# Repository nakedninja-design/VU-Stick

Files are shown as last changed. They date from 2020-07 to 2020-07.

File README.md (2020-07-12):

Party VU Stick
--------------

The Party VU Stick is a vertical LED VU meter you can stick in the ground. It listens to the FM radio channel you have set (10 presets or custom) and lights up a rainbow of colors that follow the dynamics of the music that is playing. Very easy to build and assemble, and a 8-year old child can set it up. 

STL files, source code and documentation available within 2 weeks.

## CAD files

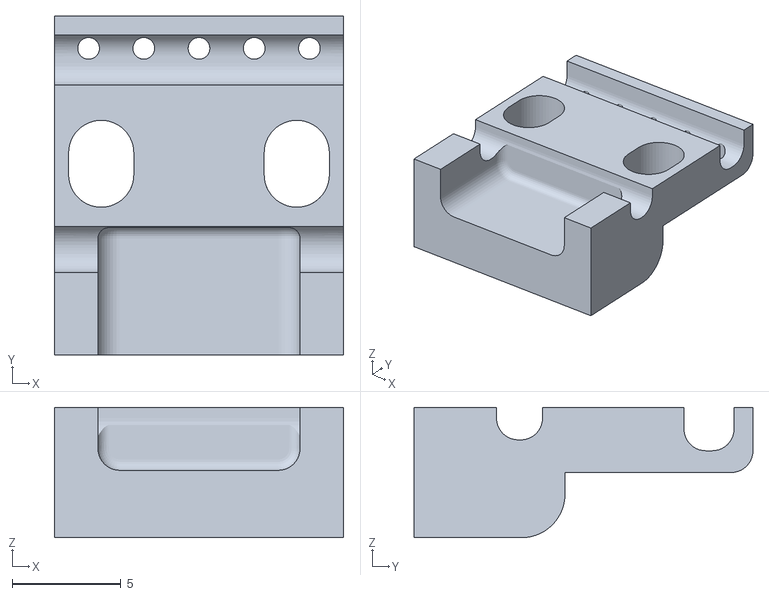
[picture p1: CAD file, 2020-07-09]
STL files/micro usb clamp.stl
13.3 x 15.6 x 6.00

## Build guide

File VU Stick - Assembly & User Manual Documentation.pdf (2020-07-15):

Copyright © 2020 Naked Ninja

### Contents

The Product | 2
Bill of Materials | 3
PCB Assembly Instructions | 4
Software Assembly & Testing | 17
3D Printing & Assembly | 19
User Manual | 33
Basic Information | 33
Connecting power | 36
Adding preset FM stations | 38
Switching between preset FM stations | 40
Setting manual FM frequency | 41
Calibrating RGB LED strip | 42
1 | Copyright © 2020 Naked Ninja

## The Product

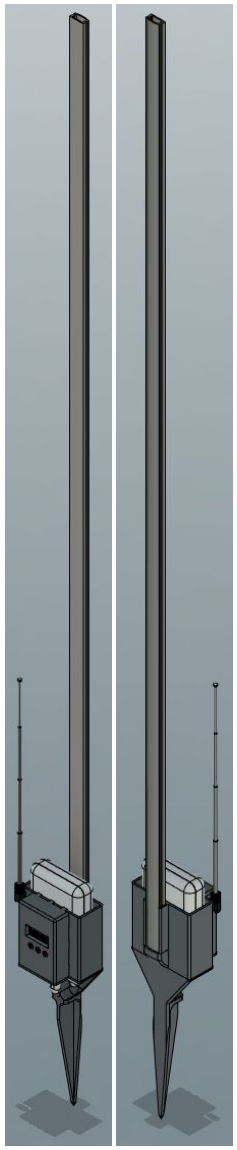
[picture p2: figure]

If you have soldering experience and are not intimidated by soldering tiny pins in tight spaces, then this build level should be appropriate for you. Make sure to use the proper soldering iron, solder wire, and solder paste for this project. Check the orientation of components before you solder them to the board. The wrong orientation may damage the components, the board, etc!

Naked Ninja does not take any responsibility and is not liable for any damage resulting from the use of products or services from Naked Ninja, be it indirect, special, incidental or consequential damages (including but not limited to damages for loss of business, loss of profits, interruption or the like).

When you have a garden party, wouldn't it be fun to have several VU meters spread throughout the garden with RGB LEDs dancing to the music you are playing? That's what the Party VU Stick is all about.

The Party VU Stick can connect to any FM radio station and dance along with the music. Want the VU Stick to dancing along with your music? It’s simple! Just add an FM transmitter to your phone and set the frequency on the VU Stick and you are done.

## Bill of Materials

We have no affiliation with AliExpress, Banggood, RS-Online, or any other supplier of components. You can use any source you like. If you want to order from another supplier, you can use the links listed below as a source for the specifications of the components.

Naked Ninja VU Stick PCB
Naked Ninja webshop (https://nakedninja.cc/)

I2C 0.91 Inch Oled Display (with PCB) https://aliexpress.com/item/32672229793.html

### 3 x Tactile Push Button 6x6x4.3mm

https://aliexpress.com/item/32960657626.html

2.54mm 3Pin Angled Male JST connector & Female Cable JST Connector (for RGB strip) https://aliexpress.com/item/4000120545240.html

5V 16MHz Arduino Pro mini
Pay attention to the A4 and A5 pin locations if you buy it from a dif erent supplier! https://www.digikey.nl/product-detail/en/sparkfun-electronics/DEV-11113/1568-1055-ND/5 140820 (https://www.digikey.nl/product-detail/en/sparkfun-electronics/DEV-11113/1568-1055-ND/5140820)

TEA5767 FM Stereo Radio Module
Pay attention to the pin locations if you buy it from a dif erent supplier! https://aliexpress.com/item/4000279468853.html

Micro USB breakout board
https://aliexpress.com/item/4000385426649.html

Powerbank with a micro USB cable https://aliexpress.com/item/4000731178541.html

RGB LED Strip - 1M 60 IP30 option (60 LEDs) https://aliexpress.com/item/32966375934.html

### 5 x Self-tapping Screw M3 8mm

https://aliexpress.com/item/32596628894.html

Resistors (2x 4.7k Ohm, 2x 10k Ohm, 1x 100k Ohm, 1x 470 Ohm) https://aliexpress.com/item/32636020144.html (Set of resistors) https://aliexpress.com/item/32847096736.html (Individual resistors)

Capacitors (1x 10uF, 1x 100uF) https://aliexpress.com/item/32500862928.html (Set of capacitors) https://aliexpress.com/item/32887486570.html (Individual capacitors)

## PCB Assembly Instructions

The following paragraphs will explain how to assemble the VU Stick PCB. Follow each step precisely to ensure everything will work properly.

1. Start with the VU Stick PCB (photo 1 & 2) and the required components named in the bill of materials.

Photo 1 & 2: Front and back view of the VU Stick V1.2 PCB

2. Place and solder the three tactile buttons on the PCB

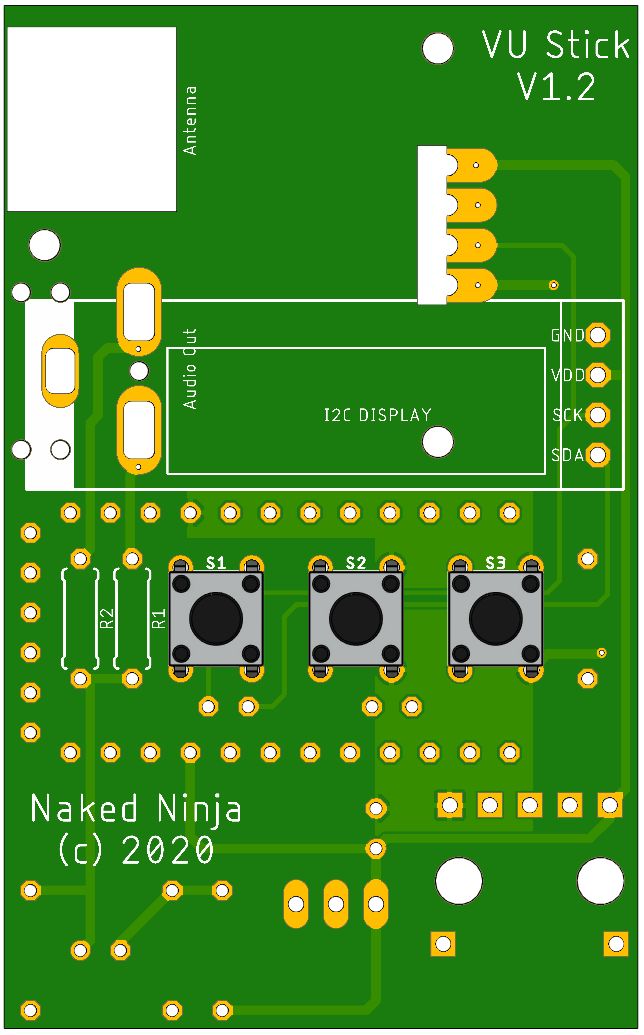
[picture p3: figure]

Photo 3: Front view of the VU Stick V1.2 PCB with tactile buttons placed and soldered.

3. Shorten the pins of the tactile buttons after they are soldered.
Note: This is done to prevent the button pins of touching the microcontroller board that will be soldered in future steps.

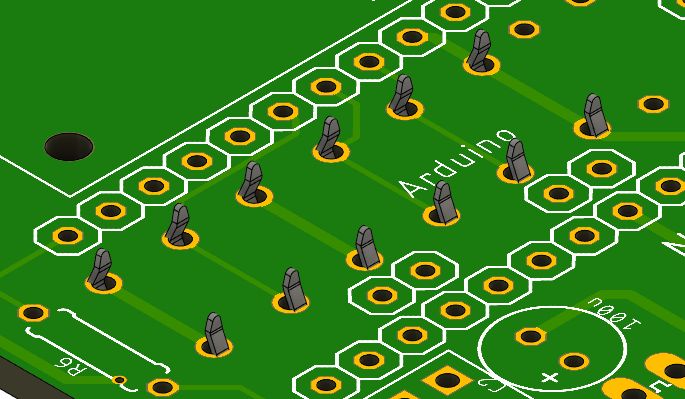
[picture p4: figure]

Photo 4: Back view of the VU Stick V1.2 PCB with tactile buttons pins sticking out of PCB.

4. Place and solder two 4.7k ohm resistors in the R1 and R2 slots next to the tactile buttons as illustrated in photo 5.

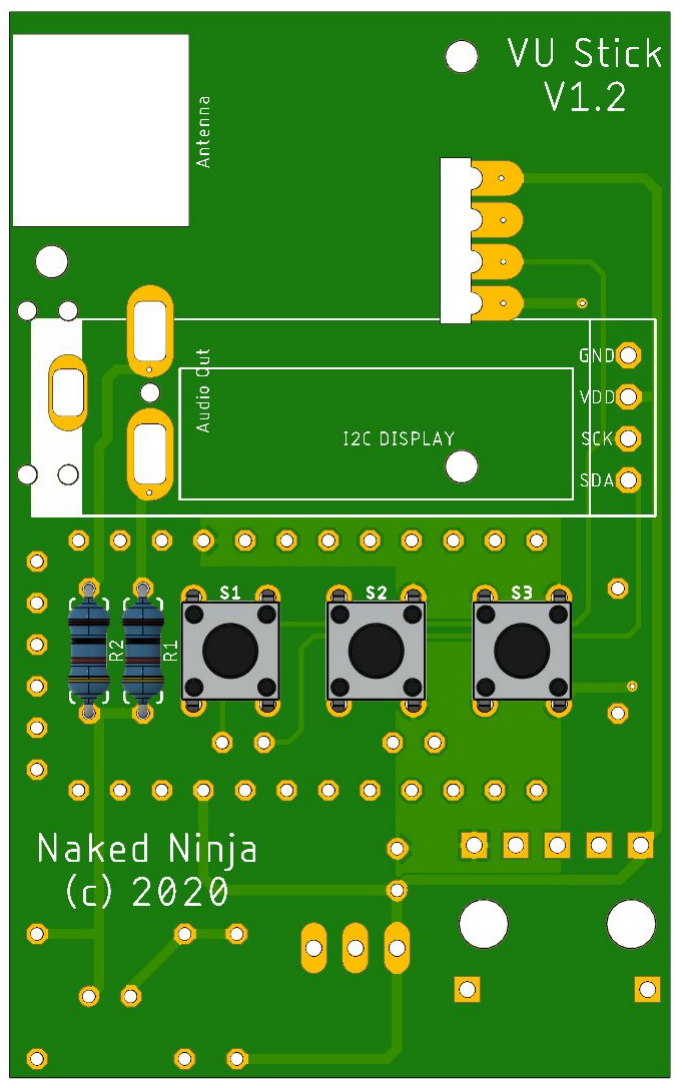
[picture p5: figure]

Photo 5: Front view of the VU Stick V1.2 PCB with resistor R1 and R2 placed and soldered.

5. Shorten the pins of the two resistors after they are soldered.
Note: This is done to prevent the resistor pins of touching the microcontroller board that will be soldered in future steps.

Photo 6: Back view of the VU Stick V1.2 PCB with shortened soldered resistor R1 and R2 pins.

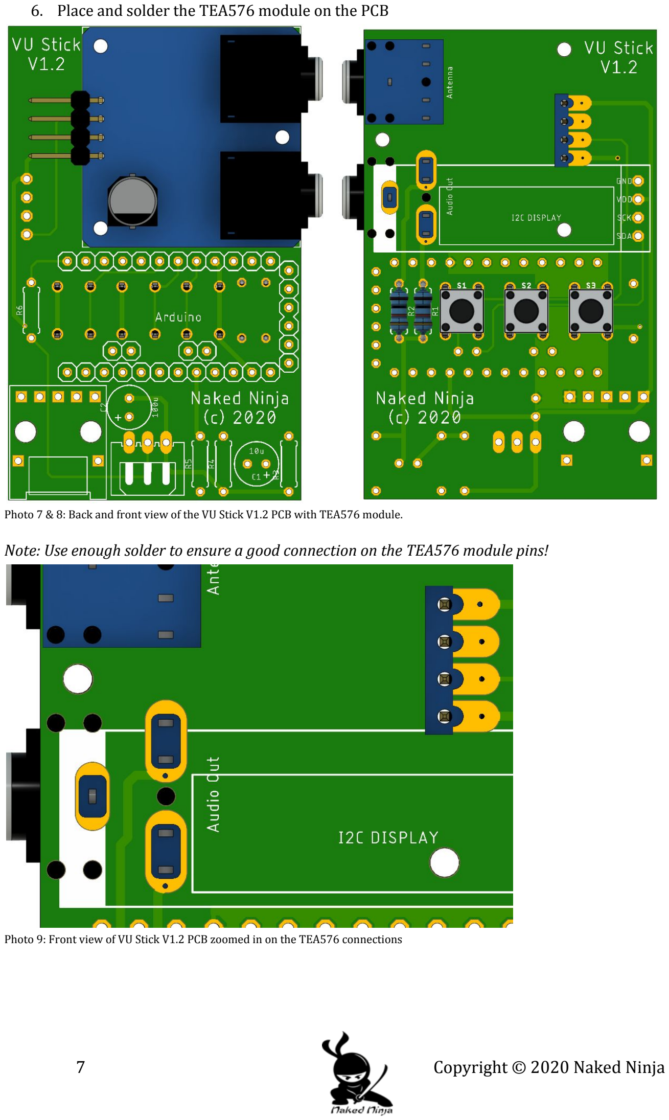
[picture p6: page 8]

6. Place and solder the TEA576 module on the PCB

Photo 7 & 8: Back and front view of the VU Stick V1.2 PCB with TEA576 module.

Note: Use enough solder to ensure a good connection on the TEA576 module pins!

Photo 9: Front view of VU Stick V1.2 PCB zoomed in on the TEA576 connections

7. Place and solder resistors in the R3, R4, R5 and R6 slots as illustrated in photo 10 with the following values per slot:
R3: 100k ohm
R4: 10k ohm
R5: 10k ohm
R6: 470 ohm

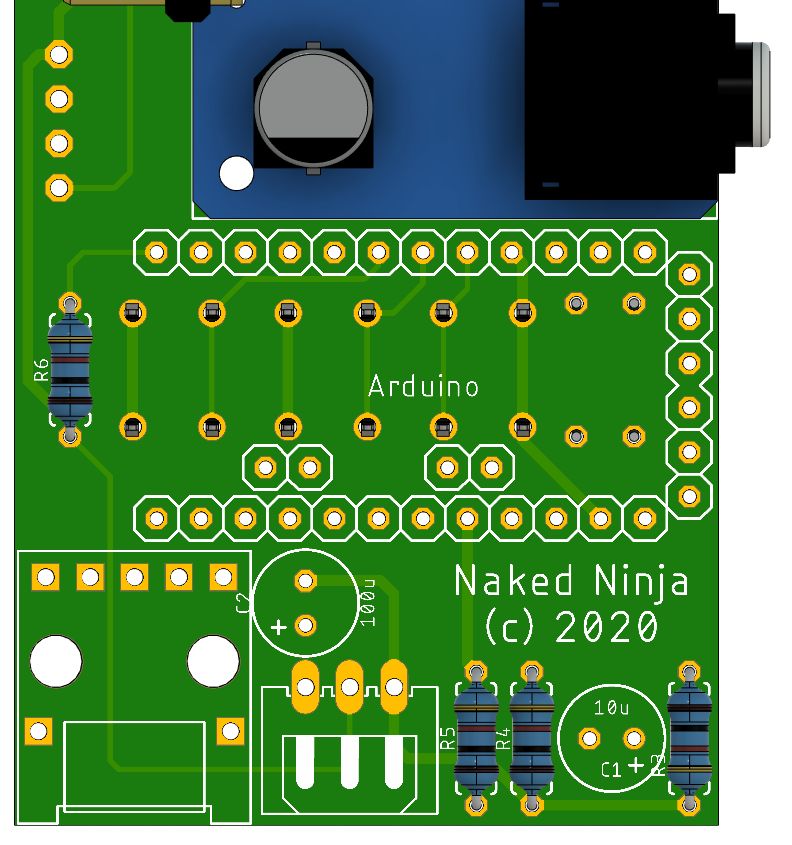
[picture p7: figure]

Photo 10: Back view of VU Stick V1.2 PCB with resistor R3, R4, R5 and R6 placed and soldered

8. Place and solder the capacitors in the C1 and C2 slots as illustrated in photo 11 and 12 with the following values per slot:
C1: 10uF
C2: 100uF
Note: Be sure to solder the plus terminal of the capacitor to the marked + on the PCB.

Photo 11: Back view of VU Stick V1.2 PCB with capacitor C1 and C2 placed and soldered

Photo 12: Angled back view of VU Stick V1.2 PCB with capacitor C1 and C2 placed and soldered

9. Place male pin header in the slots for the Arduino Pro Mini as illustrated in photo 13.

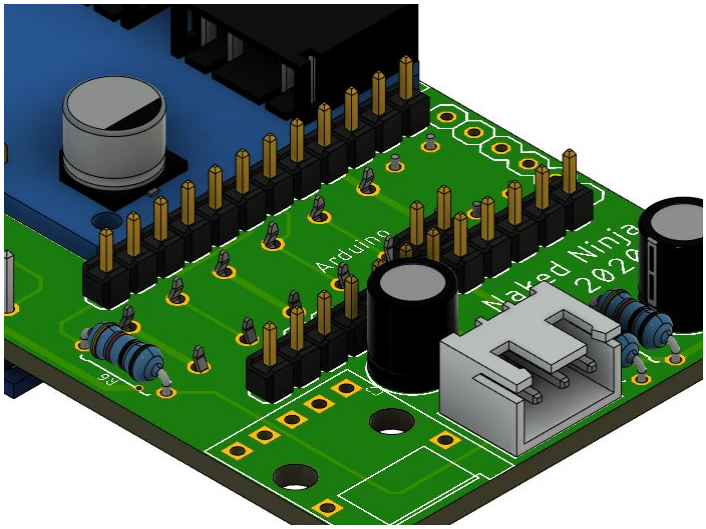
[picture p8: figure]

Photo 13: Angle back view of VU Stick V1.2 PCB with male headers

Note:
If you are using a dif erent type of the Arduino Pro Mini, make sure the following pins are connected: A3, A4(SDA), A5(SCL), D2, D3, D4, and D9.

10. Place the Arduino Pro Mini on the male headers and solder the male headers to the Arduino Pro Mini.

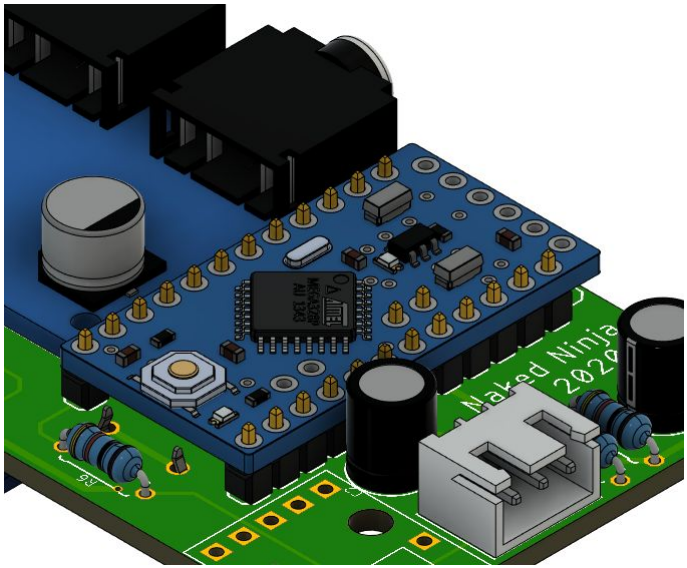
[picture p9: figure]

Photo 14: Angle back view of VU Stick V1.2 PCB with Arduino Pro Mini soldered to male headers.

11. Solder the male headers to the PCB.

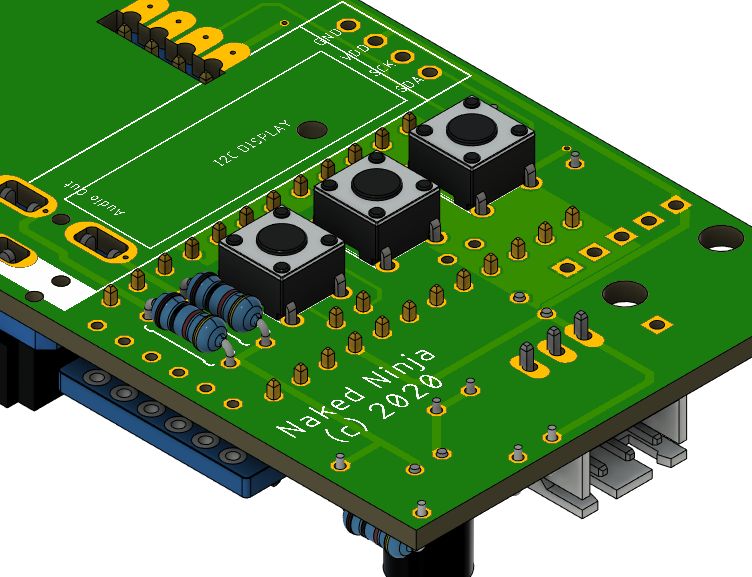
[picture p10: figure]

Photo 15: Angle top view of VU Stick V1.2 PCB with soldered male headers.

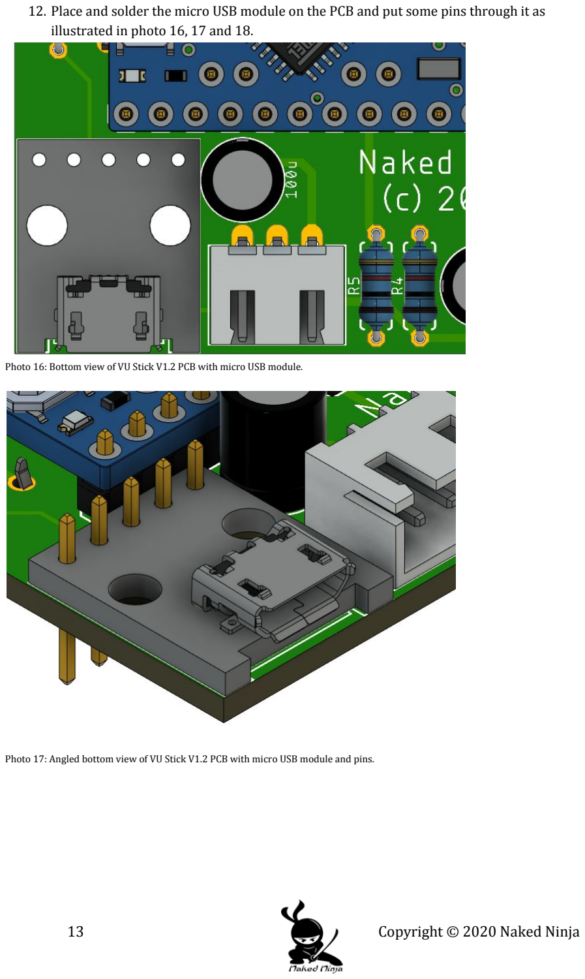
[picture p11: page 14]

12. Place and solder the micro USB module on the PCB and put some pins through it as illustrated in photo 16, 17 and 18.

Photo 16: Bottom view of VU Stick V1.2 PCB with micro USB module.

Photo 17: Angled bottom view of VU Stick V1.2 PCB with micro USB module and pins.

Photo 18: Angled top view of VU Stick V1.2 PCB with micro USB module and pins.

13. Shorten the pins on the micro USB as illustrated in photo 19 and 20 after they are soldered.

Photo 19: Angled top view of VU Stick V1.2 PCB with shortened pins on the micro USB module connection.

Photo 20: Angled top view of VU Stick V1.2 PCB with shortened pins on the micro USB module connection.

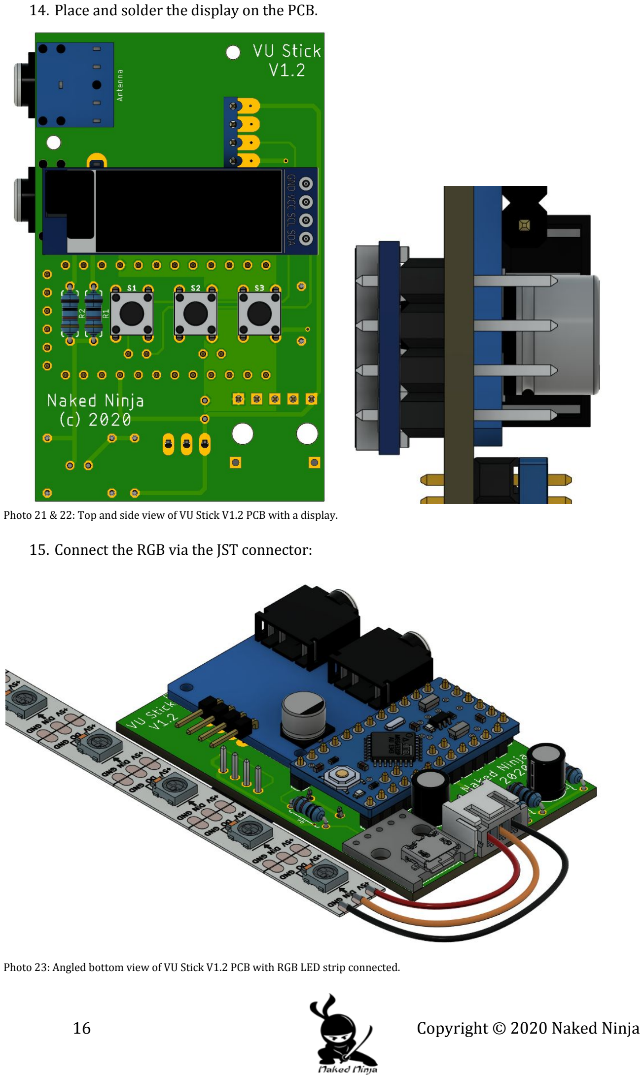
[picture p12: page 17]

14. Place and solder the display on the PCB.

Photo 21 & 22: Top and side view of VU Stick V1.2 PCB with a display.

15. Connect the RGB via the JST connector:

Photo 23: Angled bottom view of VU Stick V1.2 PCB with RGB LED strip connected.

## Software Assembly & Testing

The following paragraphs will explain how to program the VU Stick and how to configure the preset FM radio stations.

Before continuing you must acquire the following items:
- PC or laptop with the Arduino IDE
- USB to TTL converter
- USB cable (to connect the converter to the PC/laptop)
- The Arduino sketch from the Naked Ninja GitHub.

After acquiring all items follow the following steps to program and configure the VU Stick:
1. Download the Arduino sketch for the VU Stick from the Naked Ninja product page or Github.
2. Open sketch in the Arduino IDE.
3. [OPTIONAL] Replace the FM stations in the array radioStations with your preferred stations.
Notes / Warnings:
1. Max of 10 stations can be given. More than this will result in memory problems.

### 2. The first value is the frequency of the station (example: 10270 = 102.7 MHz) and the

second is the name that will show up on the display. This name must be kept short to avoid problems.

Photo 24: Arduino IDE programming screen

4. Connect the USB-TTL converter to the Arduino Pro Mini

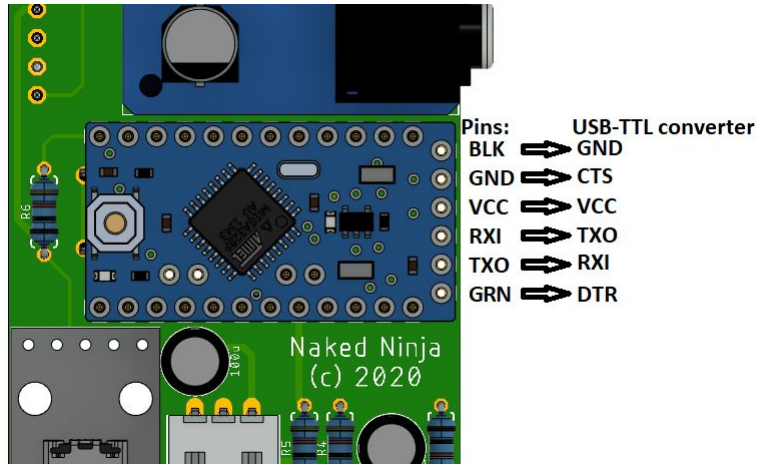
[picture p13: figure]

Photo 25: Arduino Pro Mini connection explanation

5. Connect the USB_TTL converter to the PC/Laptop.
6. Select the correct programming parameters.
Note: The programming parameters can be found in the top of the Arduino sketch
7. Program the Arduino Pro Mini.
8. Disconnect the USB-TTL converter from the Arduino Pro Mini after the programming is completed.
9. Connect the power bank through the micro USB connector and test the PCB using the “User Manual” from this document.

## 3D Printing & Assembly

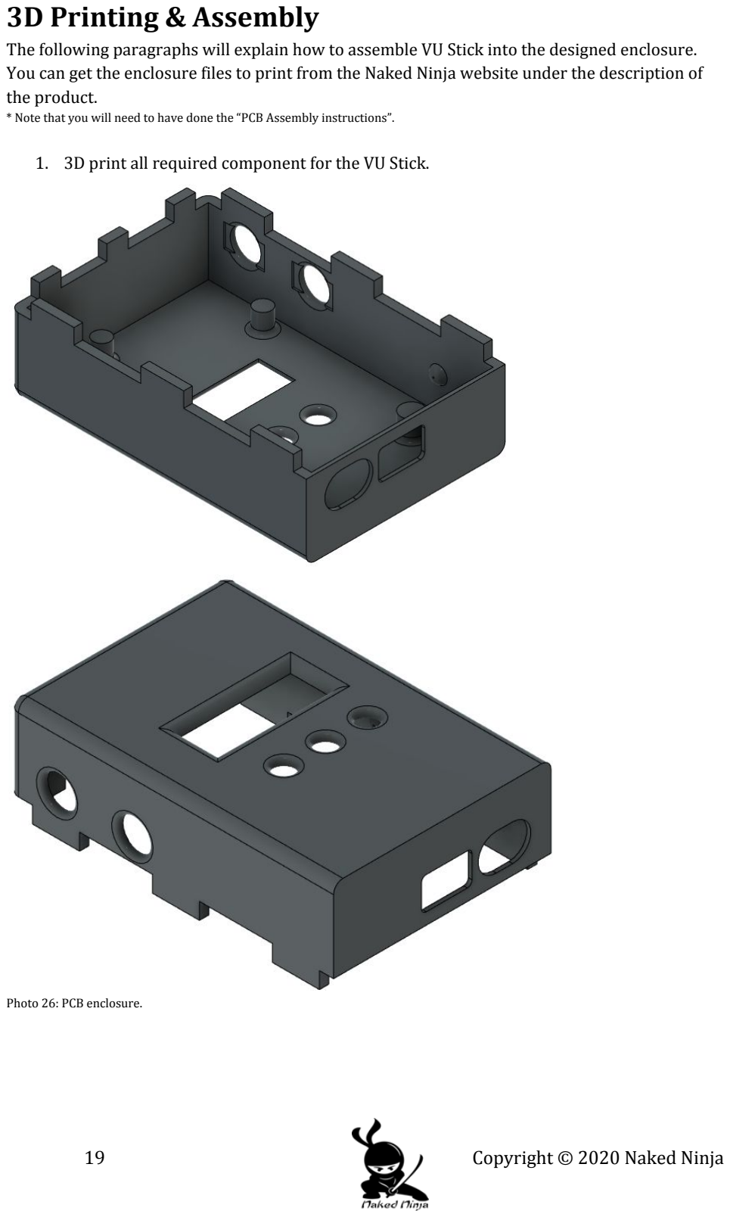
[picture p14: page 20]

The following paragraphs will explain how to assemble VU Stick into the designed enclosure. You can get the enclosure files to print from the Naked Ninja website under the description of the product.

* Note that you will need to have done the “PCB Assembly instructions”.

1. 3D print all required component for the VU Stick.

Photo 26: PCB enclosure.

Photo 27: Battery and RGB profile enclosure.

Photo 28: Spike enclosure.

Photo 29: Button caps

Photo 30: Micro USB cover.

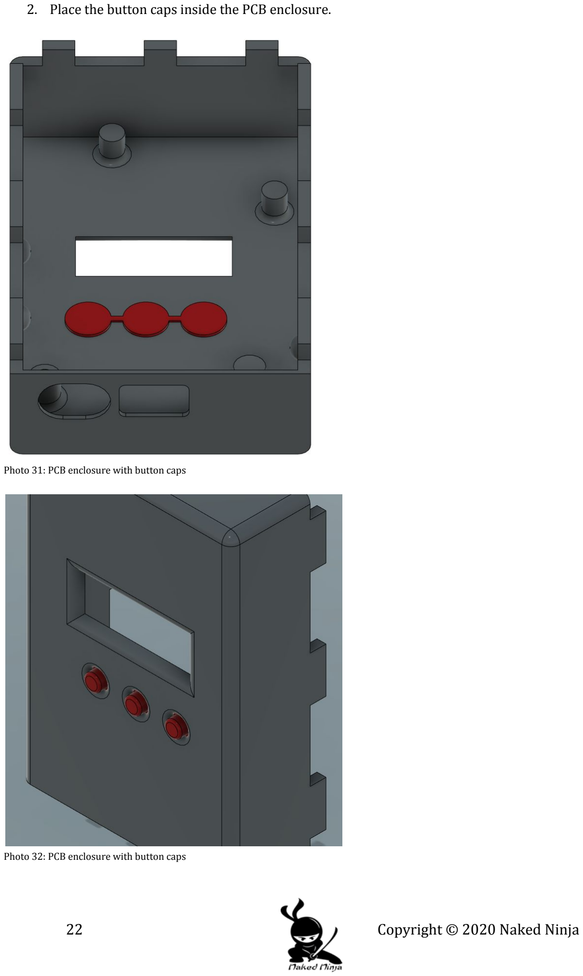
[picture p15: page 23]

2. Place the button caps inside the PCB enclosure.

Photo 31: PCB enclosure with button caps

Photo 32: PCB enclosure with button caps

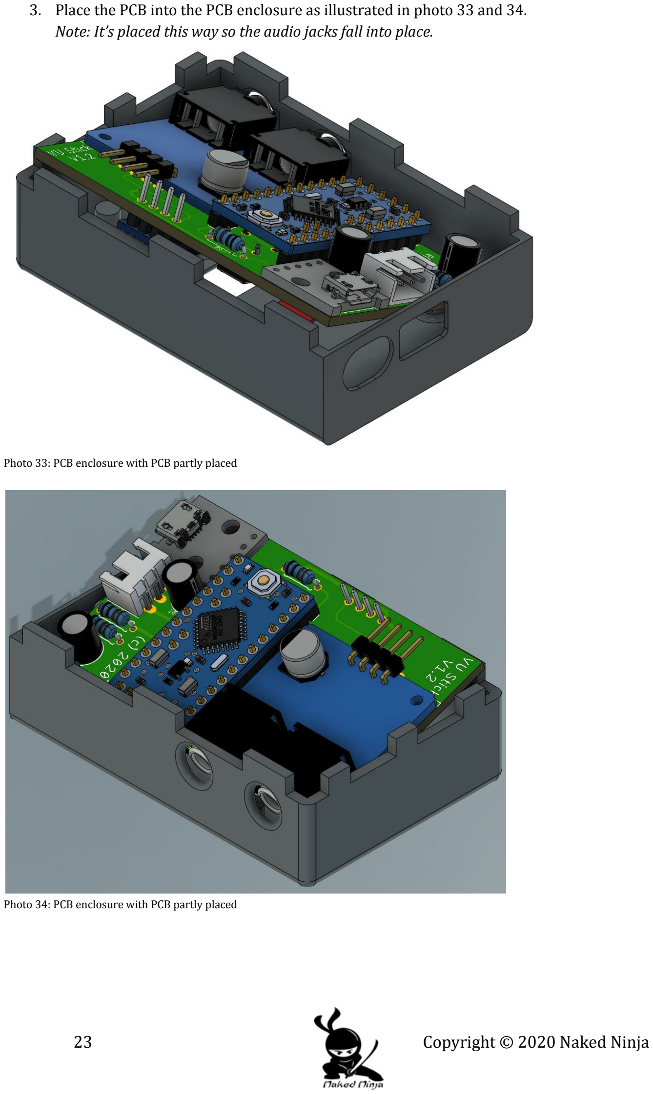
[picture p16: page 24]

3. Place the PCB into the PCB enclosure as illustrated in photo 33 and 34. Note: It’s placed this way so the audio jacks fall into place.

Photo 33: PCB enclosure with PCB partly placed

Photo 34: PCB enclosure with PCB partly placed

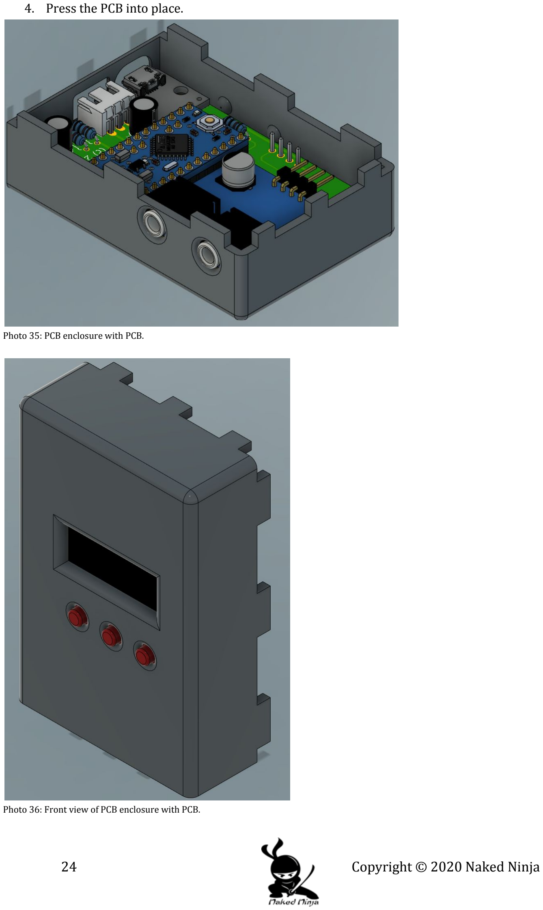
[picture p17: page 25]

4. Press the PCB into place.

Photo 35: PCB enclosure with PCB.

Photo 36: Front view of PCB enclosure with PCB.

5. Place the micro USB cover on the micro USB and screw it down with an M3 6mm screw.

Photo 37: Micro USB cover PCB enclosure with PCB.

Photo 38: Front view of PCB enclosure with PCB.

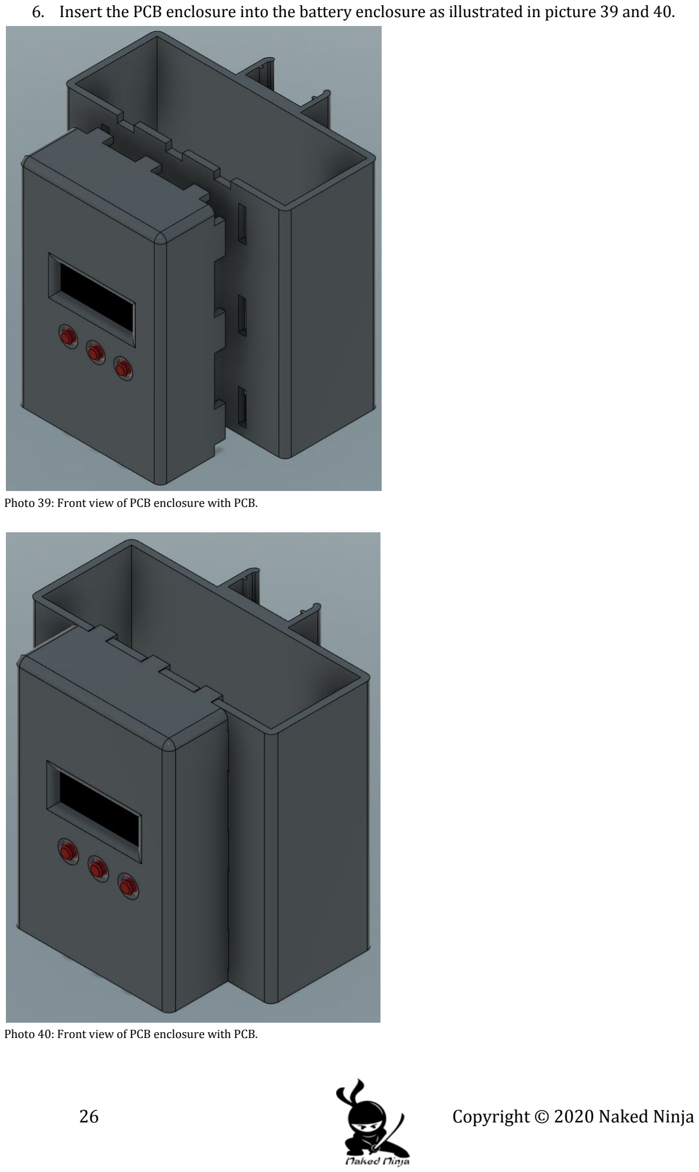
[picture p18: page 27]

6. Insert the PCB enclosure into the battery enclosure as illustrated in picture 39 and 40.

Photo 39: Front view of PCB enclosure with PCB.

Photo 40: Front view of PCB enclosure with PCB.

7. Place the RGB connector cable through the opening in the battery enclosure as illustrated in photo 41.

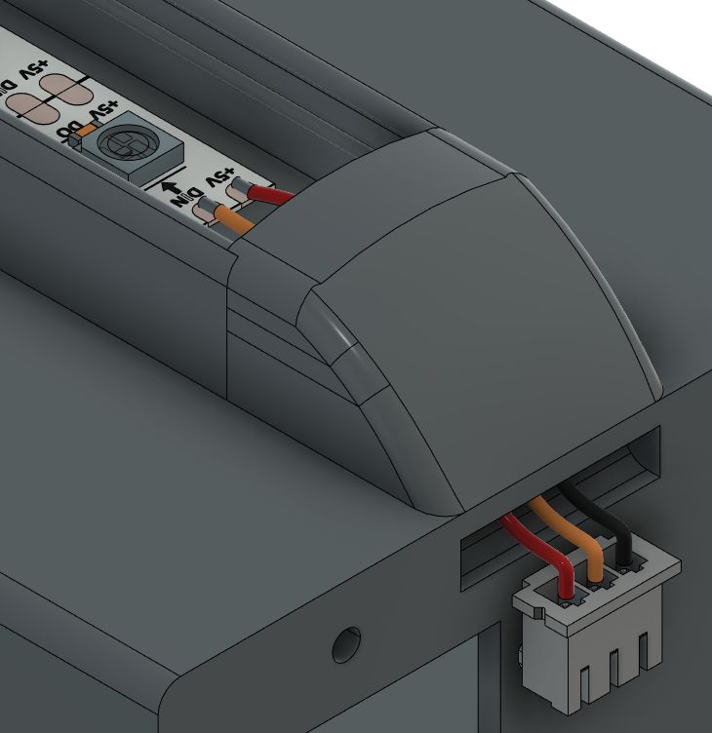
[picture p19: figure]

Photo 41: Angled view of RGB connector passed through battery enclosure.

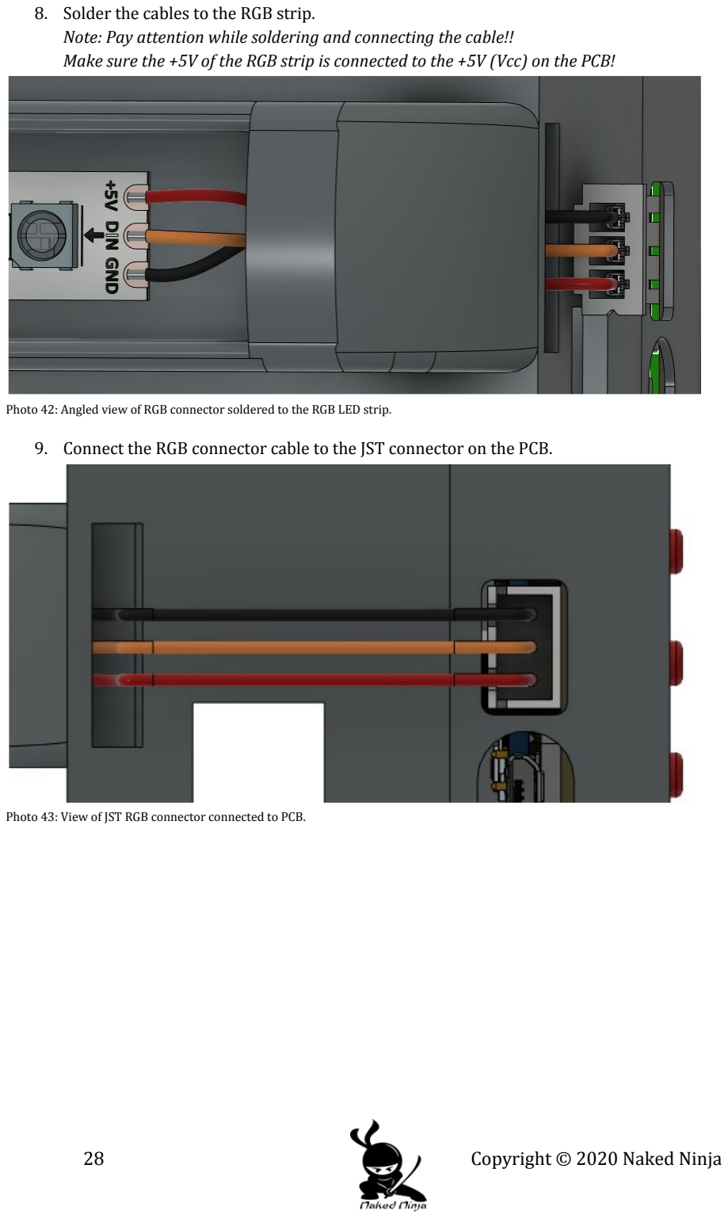
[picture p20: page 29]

8. Solder the cables to the RGB strip.
Note: Pay attention while soldering and connecting the cable!!
Make sure the +5V of the RGB strip is connected to the +5V (Vcc) on the PCB!

Photo 42: Angled view of RGB connector soldered to the RGB LED strip.

9. Connect the RGB connector cable to the JST connector on the PCB.

Photo 43: View of JST RGB connector connected to PCB.

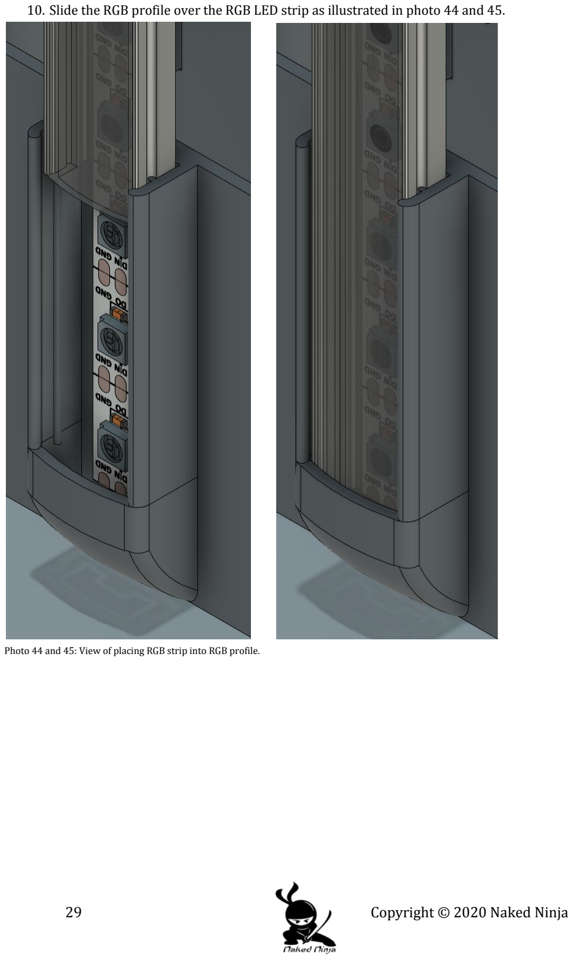
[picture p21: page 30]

10. Slide the RGB profile over the RGB LED strip as illustrated in photo 44 and 45.

Photo 44 and 45: View of placing RGB strip into RGB profile.

11. Place the spike enclosure on the bottom of the battery and PCB enclosure as illustrated in photo 46.

Photo 46: View of spike enclosure placed on battery and PCB enclosure.

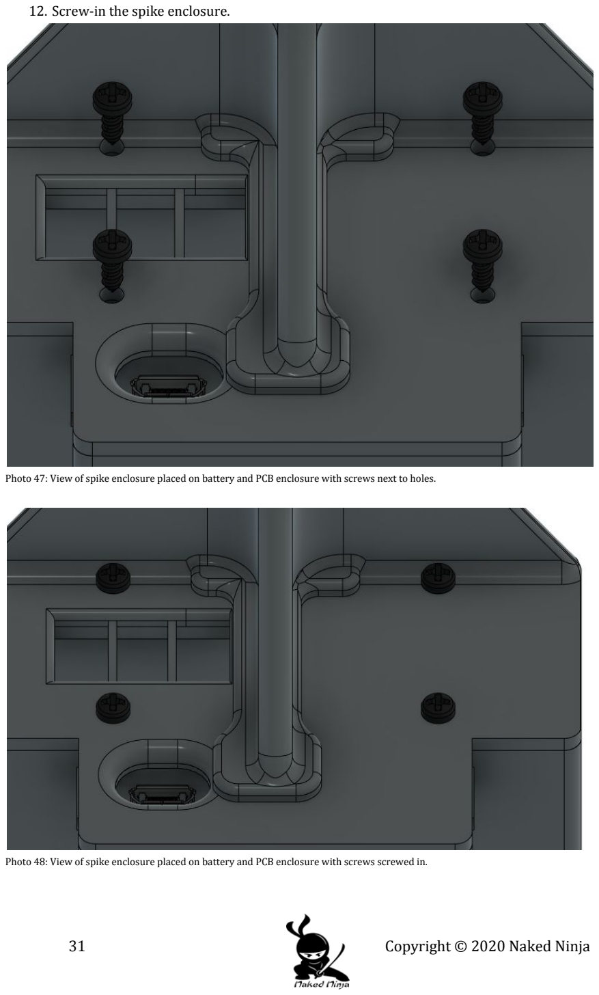
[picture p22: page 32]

12. Screw-in the spike enclosure.

Photo 47: View of spike enclosure placed on battery and PCB enclosure with screws next to holes.

Photo 48: View of spike enclosure placed on battery and PCB enclosure with screws screwed in.

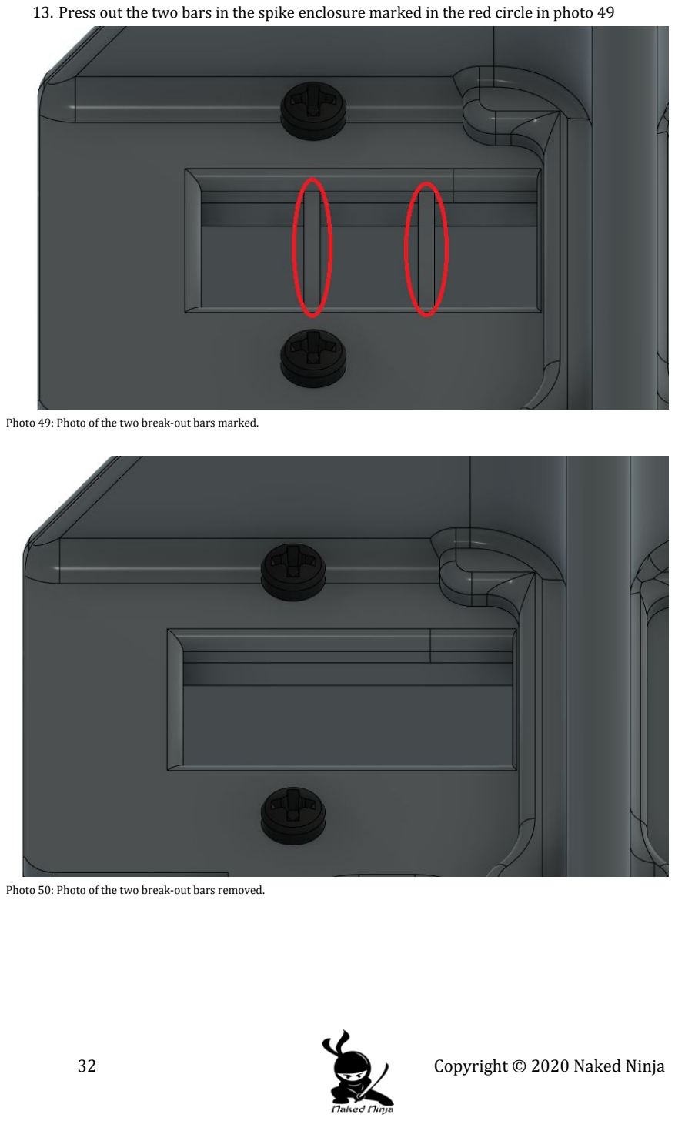
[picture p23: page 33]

13. Press out the two bars in the spike enclosure marked in the red circle in photo 49

Photo 49: Photo of the two break-out bars marked.

Photo 50: Photo of the two break-out bars removed.

## User Manual

## Basic Information

The following paragraphs will explain the basics of the VU Stick.

The VU Stick is a vertical LED VU meter you can stick in the ground. It listens to the FM radio channel you have set (10 presets or custom) and lights up a rainbow of colours that follow the dynamics of the music that is playing. Very easy to build and assemble, and an 8-year old child can set it up in the garden.

Because the device makes use of FM radio frequencies, you can also sync it with music on your phone by using a simple FM transmitter.

Button explanation:
The VU Stick has 3 buttons. These buttons are used to navigate the menu on the OLED display. The buttons, numbered in photo 51, have the following functions:
- Button 1: Select
- Button 2: Previous
- Button 3: Next

Photo 51: Front view of VU Stick with numbers marking the buttons.

Display explanation:
After powering on the VU Stick, it will display the default screen as illustrated in photo 52.

Photo 51: Default display screen.

To exit this default screen and enter the menu screen, press the “select” button.

Photo 52: Default display screen.

Here you can navigate through the menu by pressing the “previous” and “next” button. To select one of the options in the menu, press the “select” button.

The menu has the following options:
- Fixed FM
- Manual FM
- Calibrate
- Exit

These options have the following functions:
Fixed FM: In the “Fixed FM” menu, the user can switch between the preset FM radio station by pressing the “previous” and “next” button. To select and exit this menu, the user must press the “select” button on the desired FM radio station.

Manual FM: In the “Manual FM” menu, the user manually set an FM frequency between 76 and 108MHz. To select and exit this menu, the user must press the “select” button on the desired FM frequency.

Calibrate: Selecting the “Calibrate” option in the menu will bring the user to a calibration sub-menu where the user can choose between:
- Automatic: Will automatically calibrate the RGB calculation value for the currently set FM radiofrequency or station.
- Manual: Allows manual change of the RGB calculation value.
- Exit: Reverts to the main menu.

Exit: Selecting the “Exit” option in the menu will revert the display to the default screen.

## Connecting power

The following paragraphs will show you how to connect power to the VU stick
Note: Some power banks lack the required current output that is needed for the VU Stick. We recommend buying the power bank noted in the “Bill of Materials” to avoid this problem, or to buy a power bank that can at least supply 2+ amps.

Before connecting the power to the VU Stick, we recommend charging the power bank fully. After this, follow the following steps:
1. Plugin the micro USB connector.
2. Pass the USB connector through the battery enclosure.

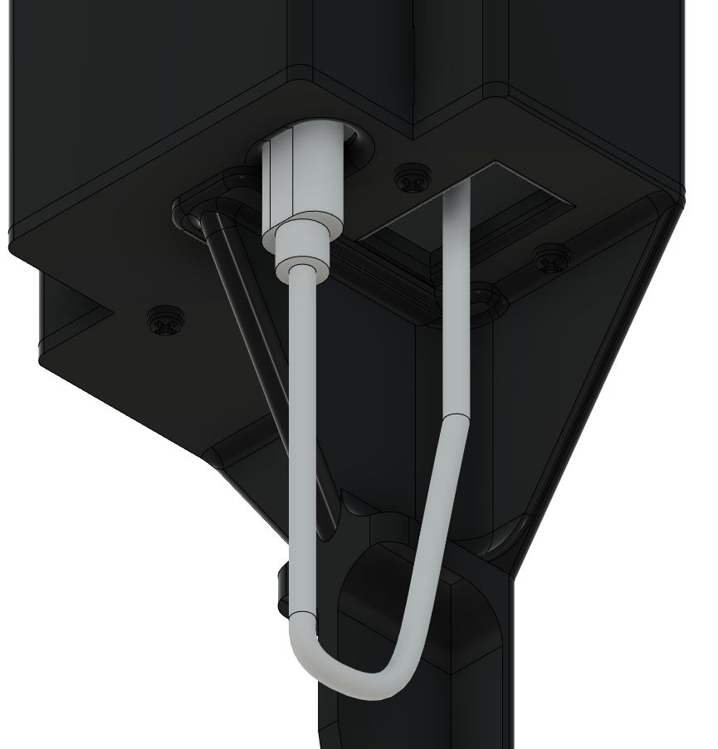
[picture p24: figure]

Photo 53: Plugged in the micro USB connector and passed through the USB connector.

3. Plug the USB connector into the power bank

Photo 54: USB connector plugged into the power bank.

4. Enable power output on the power bank.
Note: Some power banks automatically enable power output when a device is connected.
5. Slide the power bank into the battery enclosure

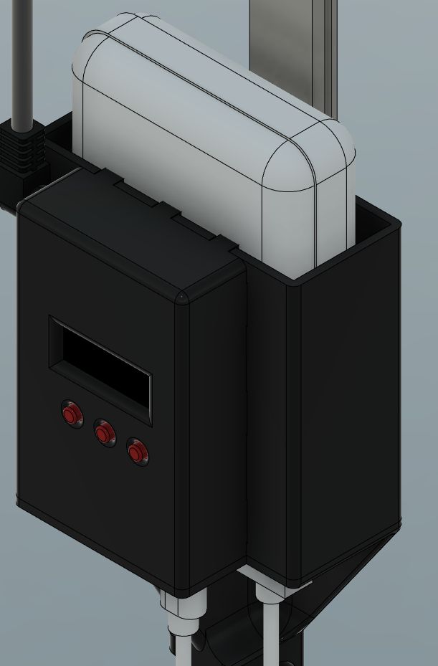
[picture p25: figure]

Photo 55: Powered VU Stick.

## Adding preset FM stations

The following paragraphs will show you add an FM station to the preset FM stations To remove or add preset FM stations, you will need to reprogram the Arduino Pro Mini. For this you will require the following:
- PC or laptop with the Arduino IDE
- USB to TTL converter
- USB cable (to connect the converter to the PC/laptop)
- The Arduino sketch from the Naked Ninja GitHub.

After acquiring all items follow the following steps to add or remove FM stations:
1. Download and open the Arduino sketch for the VU Stick from the Naked Ninja product page or Github.
2. Scroll down to the “radioStations” matrix shown in photo 56.

Photo 56: Arduino IDE programming screen
3. Replace the FM stations in the array radioStations with your preferred stations. The first value is the frequency of the station, for example, 10270 would mean a frequency of 102.7 MHz.
The second is the name that will show up on the display.
Warnings:
1. Max of 10 stations can be given. More than this will result in memory problems.

### 2. This name for the radio station must be kept short to avoid problems displaying

the radio station name on the OLED display.

4. Connect the USB-TTL converter to the Arduino Pro Mini

Photo 57: Arduino Pro Mini connection explanation

5. Connect the USB_TTL converter to the PC/Laptop.
6. Select the correct programming parameters.
Note: The programming parameters can be found in the top of the Arduino sketch
7. Program the Arduino Pro Mini
8. Disconnect the USB-TTL converter from the Arduino Pro Mini after the programming is completed

## Switching between preset FM stations

The following paragraphs will explain how to switch between the preset FM radio stations.

After powering on the VU Stick, it will display the default screen as illustrated in photo 58.

Photo 58: Default display screen.

To exit this default screen and enter the menu screen, press the “select” button.

Photo 59: Default display screen.

Select the “Fixed FM” option in the menu by navigating through the menu with the “previous” and “next” buttons and selecting the option with the “select” button.

Here you will be presented with the preset FM stations. You can navigate through the station with the “previous” and “next” buttons and exit the screen with the “select” button.

Note: The current station is instantly switched while going through the preset FM stations.

## Setting manual FM frequency

The following paragraphs will explain how to manually set

After powering on the VU Stick, it will display the default screen as illustrated in photo 60.

Photo 60: Default display screen.

To exit this default screen and enter the menu screen, press the “select” button.

Photo 61: Default display screen.

Select the “Manual FM” option in the menu by navigating through the menu with the “previous” and “next” buttons and selecting the option with the “select” button.

Notes:
- The frequency can be set between 76 and 108MHz.
- The current frequency is instantly used while switching frequencies.

## Calibrating RGB LED strip

The following paragraphs will explain how to calibrate the RGB LED strip.

After powering on the VU Stick, it will display the default screen as illustrated in photo 62.

Photo 62: Default display screen.

To exit this default screen and enter the menu screen, press the “select” button.

Photo 63: Default display screen.

Select the “Calibrate” option in the menu by navigating through the menu with the “previous” and “next” buttons and selecting the option with the “select” button.

You will be presented a new menu with the following options:
- Automatic
- Manual
- Exit

Selecting the “Automatic” option will automatically calibrate the RGB calculation value for the currently set FM radiofrequency or station. After the calibration is done, the device will notify you with the message “Product Calibrated” and return to the main menu afterwards.

Selecting the “Manual” option will prompt you with the current set RGB calculation value. This value can then be changed by using the “previous” and “next” buttons. Increasing the value will decrease the location of the highest peak of the RGB LED’s, and decreasing the value will increase this peak.

Selecting the “Exit” option will return the user to the main menu,

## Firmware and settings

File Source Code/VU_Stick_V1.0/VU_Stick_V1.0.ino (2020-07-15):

/* 
 * VU Stick V1.0
 * by: Naked Ninja
 * 
 * Uploading:
 *  - Board:      Arduino Pro Mini
 *  - Processor:  ATmega328P (5V, 16MHz)
 *  - Programme:  AVR ISP
 * 
 * Connections:
 *  - Buttons:
 *    * Button 1 (select) - D2
 *    * Button 2 (prev)   - D3
 *    * Button 3 (next)   - D4
 *    (The buttons make use of the internal pullup in the ATmega328P)
 *  - Display:
 *    * GND - GND
 *    * VCC - 5V
 *    * SCL - A5 (SCL)
 *    * SDA - A4 (SDA)
 *  - Tea5767:
 *    * VCC - 5V
 *    * SDA - A4 (SDA)
 *    * SCL - A5 (SCL)
 *    * GND - GND
 *  - RGB LED Strip:
 *    * VCC   - 5V
 *    * DATA  - D9
 *    * GND   - GND
 * 
 * Tea5767 Audio Sampling ciruit:
 * 
 *                            [5V]----(10K Ohm)---|     |-------------|
 * |----------|                                   |     | ATmega328P  |
 * |        L |--(1k Ohm)---|          +|10uF|-   |     |             |
 * |TEA5767   |             |-------|---|Cap |----|-----|A3           |
 * |        R |--(1k Ohm)---|       |             |     |             |
 * |----------|                     |             |     |             |
 *                     |(100K Ohm)--|             |     |             |
 *                     |                          |     |             |
 *               [GND]-|--------------(10K Ohm)---|     |-------------|
 *                            
 * 
 */

//Libraries
#include <avr/pgmspace.h>
#include <Adafruit_GFX.h>
#include <Adafruit_SSD1306.h>
#include <EEPROM.h>
#include <SPI.h>
#include <TEA5767.h>
#include <Wire.h>
#include <Adafruit_NeoPixel.h>

//Serial debugging
#define DEBUG false             // Flag to enable/disable debugging
#define Serial if(DEBUG)Serial 

//Preset FM Radio Stations.
char* const radioStations[][2] PROGMEM= {
  {"8860", "Slam FM"},        //88.6 MHz
  {"8930", "Radio West"},     //89.3 MHz
  {"9050", "Arrow Jazz FM "}, //90.5 MHz
  {"9180", "FunX"},           //91.8 MHz
  {"9390", "Megastad FM"},    //93.9 MHz 
  {"9470", "Radio 4 "},       //94.7 MHz
  {"9680", "3FM"},            //96.8 MHz
  {"10040", "Q Music"},       //100.4 MHz
  {"10150", "Sky Radio"},     //101.5 MHz
  {"10270", "Radio 538"}      //102.7 MHz
};

//Preset array size calculation
//#define ARRAY_COLUMNS ((int) sizeof(radioStations[0]) / sizeof(radioStations[0][0]) )
#define ARRAY_ROWS    ((int) sizeof(radioStations)    / sizeof(radioStations[0])    )

//Button pin definitions 
#define BUTTON_SELECT  2
#define BUTTON_PREV  3
#define BUTTON_NEXT  4
#define BUTTON_DEBOUNCE  100

//0.91 inch OLED display settings
#define SCREEN_WIDTH  128 // OLED display width, in pixels
#define SCREEN_HEIGHT 32  // OLED display height, in pixels
#define OLED_RESET    4

//EEPROM check value & default EEPROM values
#define EEPROM_CHECK        8888  // EEPROM Flag
#define DEFAULT_FIXED_FM    0     // Default fixed FM station
#define DEFAULT_MANUAL_FM   7600  // Default manual FM frequency
#define DEFAULT_CALIBRATION 140   // Default RGB Calibration value
#define DEFAULT_LAST_MODE   0     // 0 = Fixed FM, 1 = Manual FM

//Last Mode options
#define FIXED_FM  0
#define MANUAL_FM 1

//Display Modes
#define DISPLAY_HOME_SCREEN 0 // Home/Default screen
#define DISPLAY_MENU    1     // Menu screen
#define DISPLAY_FIXED_FM  2   // Fixed FM switching screen
#define DISPLAY_MANUAL_FM 3   // Manual FM switching screen
#define DISPLAY_CALIBRATE 4   // Calibration option screen
#define DISPLAY_CALIBRATE2  5 // Manual or Fixed FM screen
#define DISPLAY_CALIBRATE3  6 // Fixed calibration success screen

//RGB settings
#define SAMPLE_PIN  A3        // Audio sampling pin
#define SAMPLE_WINDOW  25     // Sample window width in mS (50 mS = 20Hz)
#define PEAK_FALL   6         // Rate of peak falling dot
#define NUM_LEDS    60        // Number of RGB LEDS  
#define RGB_OUT_PIN 9         // RGB data pin
#define BRIGHTNESS  25        // RGB brightness setting. The higher the brightness, the higher the power consumption.
#define COLOR_START 0         // Required value for RGB LED control
#define COLOR_FROM  0         // Required value for RGB LED control
#define COLOR_TO    255       // Required value for RGB LED control
#define CALIBRATION_MIN   50  // Minimum calibration value
#define CALIBRATION_MAX   500 // Maximum calibration value
#define CALIBRATION_LOOPS 100 // Amount of time RGBControl() is executed to get samples.
#define CALIBRATION_STEPS 10  // 

//Timeouts
#define TIMEOUT_MENU  10000  // Main menu timeout time in mS

//Class creations
TEA5767 radio;
Adafruit_SSD1306 display(SCREEN_WIDTH, SCREEN_HEIGHT, &Wire, OLED_RESET);
Adafruit_NeoPixel RGB_strip = Adafruit_NeoPixel(NUM_LEDS, RGB_OUT_PIN, NEO_GRB + NEO_KHZ800);

//Variables
int displayMode, displayState1, displayState2, displayState3, displayState4, selected, selected2;
int fixedFM, manualFM, calibration, lastMode;
int peakToPeakMem, peak, dotCount;

//Flags
bool menuFlag = false;

//Interrupt function to exit home/default screen
void pin_ISR(){
  delay(BUTTON_DEBOUNCE);                 
  if (digitalRead(BUTTON_SELECT) == LOW) {
    menuFlag = true;
    detachInterrupt(digitalPinToInterrupt(BUTTON_SELECT));
  }
  else {
    menuFlag = false;
    attachInterrupt(digitalPinToInterrupt(BUTTON_SELECT), pin_ISR, FALLING);
  }
}

//RGB LED calibration value
void calibrate(){ 
  Serial.println(F("calibrate()"));
  peak = 0;
  peakToPeakMem = 0;
  for (int i = 0; i < CALIBRATION_LOOPS; i++){
    RGBControl();
    calibration = (10*round(peakToPeakMem/10)) + CALIBRATION_STEPS;
  }
  Serial.println(calibration);
  peak = 0; 

  Serial.println(F("\tCalibration value recalibrated"));
  Serial.println();
}

//TEA5767 initialization
void radioSetup(){
  Serial.println(F("radioSetup()"));
  radio.init();                     // Initialize the Radio
  radio.setMono(false);             // Set mono as false
  radio.debugEnable(false);         // Enable information to the Serial port
  Serial.println(F("\tradio set"));
     
  if(lastMode == FIXED_FM){
    radio.setBandFrequency(RADIO_BAND_FM , (atoi((char *) pgm_read_word (&radioStations[fixedFM][0]))));  //Send set frequency to TEA module
    Serial.print(F("\tSet frequentie: "));
    Serial.println(radio.getFrequency());
  }
  else if (lastMode == MANUAL_FM){
    radio.setBandFrequency(RADIO_BAND_FM , manualFM);  //Send set frequency to TEA module
    Serial.print(F("\tSet frequentie: "));
    Serial.println(radio.getFrequency());
  } 
  Serial.println();
}

//Button control funtion
void buttonControl(){
  Serial.println(F("buttonControl()"));
  
  // Clear RGB LED Strip
  for(int i = RGB_strip.numPixels(); i >= 0; i--) {
    RGB_strip.setPixelColor(i, 0); 
  }
  RGB_strip.show();

  // Set variables and timers
  bool check = false;
  unsigned long buffT = millis();     //Buffer starter time
  unsigned long currentT = millis();  //Buffer current time
  selected = 1;
  selected2 = 1;
  displayState1 = 1;
  displayState2 = 0;
  displayState3 = 1;
  displayState4 = 0;
  displayMode = DISPLAY_MENU;

  // Display menu
  displayControl(displayMode);
  delay(500);                   // Debounce to ensure it enters menu properly

  // Main button menu loop
  Serial.println(F("\tEntering button loop"));
  while(currentT<(buffT+TIMEOUT_MENU)){       //Go into while loop while current time is smaller than starter time + TIMEOUT_MENU
    if (selected2 == 1 && displayMode == DISPLAY_CALIBRATE2) {
      RGBControl();
    }
    
    if (digitalRead(BUTTON_SELECT) == LOW) { 
      delay(BUTTON_DEBOUNCE);                
      if (digitalRead(BUTTON_SELECT) == LOW) {
        if (displayMode == DISPLAY_MENU) {
          buffT = millis();             //Update starter time
          switch(selected){
            case 1: //Fixed FM
              displayMode = DISPLAY_FIXED_FM;
              lastMode = FIXED_FM;
              radio.setBandFrequency(RADIO_BAND_FM , (atoi((char *) pgm_read_word (&radioStations[fixedFM][0]))));  //Send set frequency to TEA module
              Serial.print(F("\tSet frequentie: "));
              Serial.println(radio.getFrequency());
              break;
            case 2: //Manual FM
              displayMode = DISPLAY_MANUAL_FM;
              lastMode = MANUAL_FM;
              radio.setBandFrequency(RADIO_BAND_FM , manualFM);  //Send set frequency to TEA module
              Serial.print(F("\tSet frequentie: "));
              Serial.println(radio.getFrequency()); 
              break;
            case 3: //Calibrate
              displayMode = DISPLAY_CALIBRATE;
              Serial.print(F("\tEntering calibrate menu"));
              break;
            case 4: //Exit
              check = true;
              break;
          }
          displayControl(displayMode);
        }
        else if (displayMode == DISPLAY_FIXED_FM) {
          displayMode = DISPLAY_MENU;
        }
        else if (displayMode == DISPLAY_MANUAL_FM) {
          displayMode = DISPLAY_MENU;
        }
        else if (displayMode == DISPLAY_CALIBRATE) {
          if (selected2 == 3){      // exit
            displayMode = DISPLAY_MENU;
          }
          else if (selected2 == 2) { // automatic
            displayMode = DISPLAY_CALIBRATE2;
          }
          else if (selected2 == 1) { // manual
            displayMode = DISPLAY_CALIBRATE2;
          }
        }
        else if (displayMode == DISPLAY_CALIBRATE2) {
          if (selected2 == 1) {
            displayMode = DISPLAY_CALIBRATE;
          }
        }
        displayControl(displayMode);
      }
    }
    if (digitalRead(BUTTON_PREV) == LOW) {   
      delay(BUTTON_DEBOUNCE);                
      if (digitalRead(BUTTON_PREV) == LOW) { 
        buffT = millis();                     //Update starter time
        Serial.println(F("\tBUTTON_PREV"));
        if (displayMode == DISPLAY_MENU) {
          displayState1 = 1;
          if (displayState2 <= 0) {
            displayState2 = 3;
          } else {
            displayState2--;
          }
        }
        else if (displayMode == DISPLAY_FIXED_FM) {
          if (fixedFM > 0) {        // If fixed station is higer than 0
            fixedFM = fixedFM - 1;  // Move to previous in list
          }
          else if(fixedFM <= 0){     // If fixed station is smaller than or equal to 0
            fixedFM = (ARRAY_ROWS-1);// Frequency set to last value in list
          }
          radio.setBandFrequency(RADIO_BAND_FM , (atoi((char *) pgm_read_word (&radioStations[fixedFM][0]))));  //Send set frequency to TEA module
          Serial.print(F("\tSet frequentie: "));
          Serial.println(radio.getFrequency());
        }
        else if (displayMode == DISPLAY_MANUAL_FM) {
          if (manualFM > 7600) {      // If frequency is higer than 7600
            manualFM = manualFM - 10; // Substract 10
          }
          else if(manualFM <= 7600){  // If frequency is 7600
            manualFM = 10800;         // Frequency set to 10800
          }
          radio.setBandFrequency(RADIO_BAND_FM , manualFM);  //Send set frequency to TEA module
          Serial.print(F("\tSet frequentie: "));
          Serial.println(radio.getFrequency());
        }
        else if (displayMode == DISPLAY_CALIBRATE) {
          displayState3 = 1;
          if (displayState4 <= 0) {
            displayState4 = 2;
          } else {
            displayState4--;
          }
        }
        else if (displayMode == DISPLAY_CALIBRATE2) {
          if (calibration > CALIBRATION_MIN) {     
            calibration = calibration - CALIBRATION_STEPS;
          }
          else if(calibration < CALIBRATION_MIN){  
            calibration = CALIBRATION_MAX;
          }
          peak=0;
          delay(100);
          Serial.print(F("\tSet calibration: "));
          Serial.println(calibration);
        }
        displayControl(displayMode);
      }
    }
    if (digitalRead(BUTTON_NEXT) == LOW) {
      delay(BUTTON_DEBOUNCE);             
      if (digitalRead(BUTTON_NEXT) == LOW) {
        buffT = millis();                   //Update starter time
        Serial.println(F("\tBUTTON_NEXT"));
        if (displayMode == DISPLAY_MENU) {
          displayState1 = 0;
          if (displayState2 >= 4) {
            displayState2 = 0;
          } else {
            displayState2++;
          }
        }
        else if (displayMode == DISPLAY_FIXED_FM) {
          if (fixedFM < (ARRAY_ROWS-1)) {   // If fixed station is lower than array length
            fixedFM = fixedFM + 1;          // Move to next in list
          }
          else if(fixedFM >= (ARRAY_ROWS-1)){ // If fixed station is higher than or equal to array length
            fixedFM = 0;                      // Set fixedFM to first station in list
          }
          radio.setBandFrequency(RADIO_BAND_FM , (atoi((char *) pgm_read_word (&radioStations[fixedFM][0]))));  // Send set frequency to TEA module
          Serial.print(F("\tSet frequentie: "));
          Serial.println(radio.getFrequency());
        }
        else if (displayMode == DISPLAY_MANUAL_FM) {
          if (manualFM < 10800) {     // If frequency is lower than 10800
            manualFM = manualFM + 10; // Add 10
          }
          else if(manualFM >= 10800){ // If frequency is 10800
            manualFM = 7600;          // Frequency is 7600
          }
          radio.setBandFrequency(RADIO_BAND_FM , manualFM);  // Send set frequency to TEA module
          Serial.print(F("\tSet frequentie: "));
          Serial.println(radio.getFrequency());
        }
        else if (displayMode == DISPLAY_CALIBRATE) {
          displayState3 = 0;
          if (displayState4 >= 3) {
            displayState4 = 1;
          } else {
            displayState4++;
          }
        }
        else if (displayMode == DISPLAY_CALIBRATE2) {
          if (calibration < CALIBRATION_MAX) {
            calibration = calibration + CALIBRATION_STEPS; 
          }
          else if(calibration >= CALIBRATION_MAX){ 
            calibration = CALIBRATION_MIN;         
          }
          peak=0;
          delay(100);
          Serial.print(F("\tSet calibration: "));
          Serial.println(calibration);
        }
        displayControl(displayMode);
      }
    }
  
    currentT = millis();                      // Update current time
    if (selected2 == 2 && displayMode == DISPLAY_CALIBRATE2){
      calibrate();
      displayMode = DISPLAY_CALIBRATE3;
      displayControl(displayMode);
      delay(2000);
      displayMode = DISPLAY_MENU;
      displayControl(displayMode);
    }
    if (check) {
      break;
    }
  }
  saveEEPROM();       // Save settings to EEPROM
  displayControl(DISPLAY_HOME_SCREEN);  // Display home/default screen
  menuFlag = false;   // Reset menu flag
  Serial.println();   
  delay(500);
  attachInterrupt(digitalPinToInterrupt(BUTTON_SELECT), pin_ISR, LOW);
}

//Display control funtion
void displayControl(int input){
  Serial.println(F("displayControl()"));
  display.clearDisplay();         // Clear display
  display.setCursor(0, 0);        // Set cursor to base point
  switch (input){
    case DISPLAY_HOME_SCREEN: //Home Screen
      display.println(F("VUstick by")); // Starting screen
      display.print(F("NakedNinja"));   // Starting screen
      display.display();                // Execute everything infront of this line on the display
      break;
    case DISPLAY_MENU: //Menu
      if (displayState1 == 0) {
        switch (displayState2){
          case 1:
            display.println(F(" Fixed FM"));
            display.println(F(">Manual FM"));
            display.display();
            selected = 2;
            break;
          case 2:
            display.println(F(" Manual FM"));
            display.println(F(">Calibrate"));
            display.display();
            selected = 3;
            break;
          case 3:
            display.println(F(" Calibrate"));
            display.println(F(">Exit"));
            display.display();
            selected = 4;
            break;
          case 4:
            display.println(F(" Exit"));
            display.println(F(">Fixed FM"));
            display.display();
            selected = 1;
            break;
        } 
      } 
      else if (displayState1 == 1) {
        switch (displayState2){
          case 0:
            display.println(F(">Fixed FM"));
            display.println(F(" Manual FM"));
            display.display();
            selected = 1;
            break;
          case 1:
            display.println(F(">Manual FM"));
            display.println(F(" Calibrate"));
            display.display();
            selected = 2;
            break;
          case 2:
            display.println(F(">Calibrate"));
            display.println(F(" Exit"));
            display.display();
            selected = 3;
            break;
          case 3:
            display.println(F(">Exit"));
            display.println(F(" Fixed FM"));
            display.display();
            selected = 4;
            break;
        } 
      }
      break;
    case DISPLAY_FIXED_FM: //Fixed FM
      display.println(F("Channel"));   
      display.print((char *) pgm_read_word (&radioStations[fixedFM][1]));
      display.display();              
      break;
    case DISPLAY_MANUAL_FM: //Manual FM
      display.println(F("Frequency"));
      int q1 = manualFM;              
      int fp = q1 / 100;
      int sp = q1 - (fp * 100);
      display.print(fp);              
      display.print(F("."));
      display.print(sp);
      display.print(F(" Mhz"));
      display.display();             
      break;
    default:
//      Serial.println(F("\tdefault"));
      break;
  }
  switch (input){
    case DISPLAY_CALIBRATE:
      if (displayState3 == 0) {
        switch (displayState4){
          case 1:
            display.println(F(" Manual"));
            display.println(F(">Automatic"));
            display.display();
            selected2 = 2;
            break;
          case 2:
            display.println(F(" Automatic"));
            display.println(F(">Exit"));
            display.display();
            selected2 = 3;
            break;
          case 3:
            display.println(F(" Exit"));
            display.println(F(">Manual"));
            display.display();
            selected2 = 1;
            break;
        } 
      } 
      else if (displayState3 == 1) {
        switch (displayState4){
          case 0:
            display.println(F(">Manual"));
            display.println(F(" Automatic"));
            display.display();
            selected2 = 1;
            break;
          case 1:
            display.println(F(">Automatic"));
            display.println(F(" Exit"));
            display.display();
            selected2 = 2;
            break;
          case 2:
            display.println(F(">Exit"));
            display.println(F(" Manual"));
            display.display();
            selected2 = 3;
            break;
        } 
      }
    case DISPLAY_CALIBRATE2:
      if (selected2 == 1) { //manual
        display.println(F("Cal. value"));
        display.println(calibration);
        display.display();
      }
      else if (selected2 == 2) { //automatic
        display.println(F("Calibrating..."));
        display.display();
      }
      break;
    case DISPLAY_CALIBRATE3:
      display.println(F("Product"));
      display.println(F("Calibrated"));
      display.display();
      break;
    default:
//      Serial.println(F("\tdefault"));
      break;
  }
  Serial.println();
}

//Save values to EEPROM
void saveEEPROM(){
  Serial.println(F("saveEEPROM()"));
  Serial.println(F("\tSaved values"));
  Serial.print(F("\tfixedFM:"));
  Serial.println(fixedFM);
  Serial.print(F("\tmanualFM:"));
  Serial.println(manualFM);
  Serial.print(F("\tcalibration:"));
  Serial.println(calibration);
  Serial.print(F("\tlastMode:"));
  Serial.println(lastMode);

  EEPROM.put(0, EEPROM_CHECK);// Check value
  EEPROM.put(2, fixedFM);     // Save Fixed FM
  EEPROM.put(4, manualFM);    // Save Manual FM
  EEPROM.put(6, calibration); // Save calibration 
  EEPROM.put(8, lastMode);    // Save lastMode
  
  Serial.println();
}

//Load values from EEPROM
void loadEEPROM(){
  Serial.println(F("loadEEPROM()"));
  int EEPROMcheck;                  // Variable
  EEPROM.get(0, EEPROMcheck);       // Get first EEPROM value to see 
  if(EEPROMcheck == EEPROM_CHECK){  // if EEPROM is configured
    EEPROM.get(2, fixedFM);         // Fixed FM
    EEPROM.get(4, manualFM);        // Manual FM
    EEPROM.get(6, calibration);     // calibration
    EEPROM.get(8, lastMode);        // lastMode
    Serial.println(F("\tSettings successfully loaded."));
  }
  else{
    for (int i = 0 ; i < EEPROM.length() ; i++) { // Clear EEPROM
      EEPROM.write(i, 0);     
    }
    // Create all default EEPROM values
    EEPROM.put(0, EEPROM_CHECK);        // Check value
    EEPROM.put(2, DEFAULT_FIXED_FM);    // Fixed FM
    EEPROM.put(4, DEFAULT_MANUAL_FM);   // Manual FM
    EEPROM.put(6, DEFAULT_CALIBRATION); // Calibration
    EEPROM.put(8, DEFAULT_LAST_MODE);   // Last Mode
    
    // Create all default values to be used
    fixedFM = DEFAULT_FIXED_FM;
    manualFM = DEFAULT_MANUAL_FM;
    calibration = DEFAULT_CALIBRATION;
    lastMode = DEFAULT_LAST_MODE;
    
    Serial.println(F("\tEEPROM Empty."));
    Serial.println(F("\tSet and saved default value's"));
  }
  Serial.println();
}

//RGB rainbow control
uint32_t wheel(byte wheelPos) {
  wheelPos = 255 - wheelPos;
  if(wheelPos < 45) {
   return RGB_strip.Color(255 - wheelPos * 3, 0, wheelPos * 3);
} else if(wheelPos < 170) {
    wheelPos -= 85;
   return RGB_strip.Color(0, wheelPos * 3, 255 - wheelPos * 3);
  } else {
   wheelPos -= 170;
   return RGB_strip.Color(wheelPos * 3, 255 - wheelPos * 3, 0);
  }
}
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
void loop() {
  RGBControl();
  if (menuFlag) {
    Serial.println(F("loop()"));
    Serial.println(F("\tmenu"));
    Serial.println();
    buttonControl();
  }
}
